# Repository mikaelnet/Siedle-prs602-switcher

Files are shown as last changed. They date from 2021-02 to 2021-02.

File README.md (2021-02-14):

# Siedle-prs602-switcher
Switching module for Siedle PRS602 programmer. 

This is a simple relay card built for Brf Albert that enables
programming of the three Siedle sections without physically
moving the programming cable.

## Function
One of the three sections can be selected either by a push on
one of the corresponding buttons on the case or by sending the
number 1-3 followed by a carrage return on the serial port. 

The relay card has a timeout of 10 minutes after it releases
the relays. The indicating leds blinks slowly two minutes before
the timeout and blinks rapidly one minute before the timeout.
A new 10 minute period is started if the active button or 
corresponding serial command is resent.

## Content
* schematic: Eagle schematic and board layout. The scematic is also expored as a pdf.
* arduino: A simple sketch for the Arduino firmware.
* case: STL files for the case for 3D printng.
* desktop: Simple Windows Form application for controlling the switch box

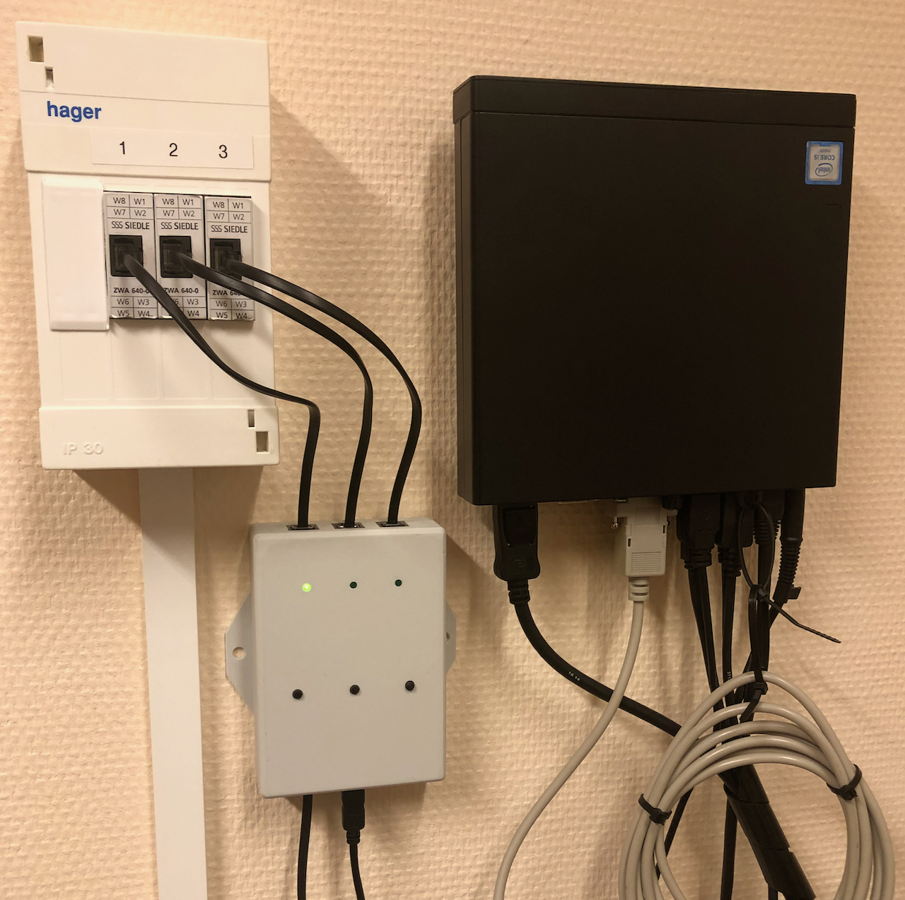
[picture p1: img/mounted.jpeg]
Mounted Switch


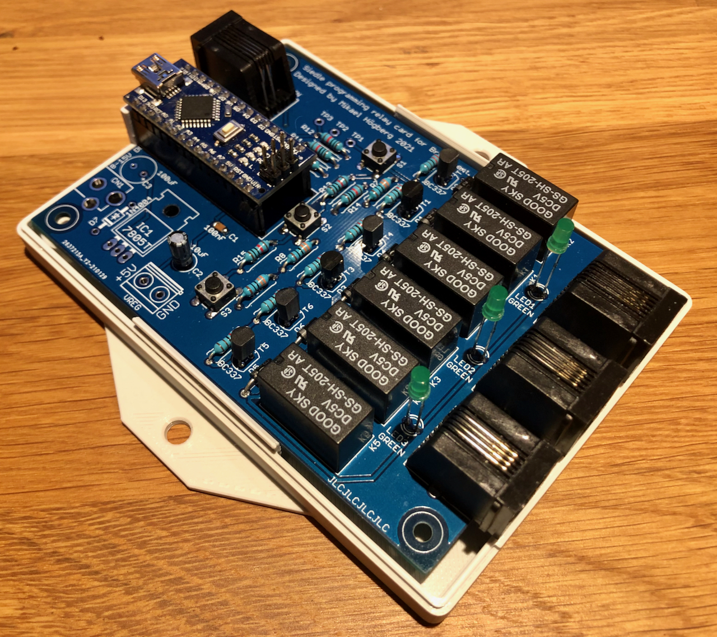
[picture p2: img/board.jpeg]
Board


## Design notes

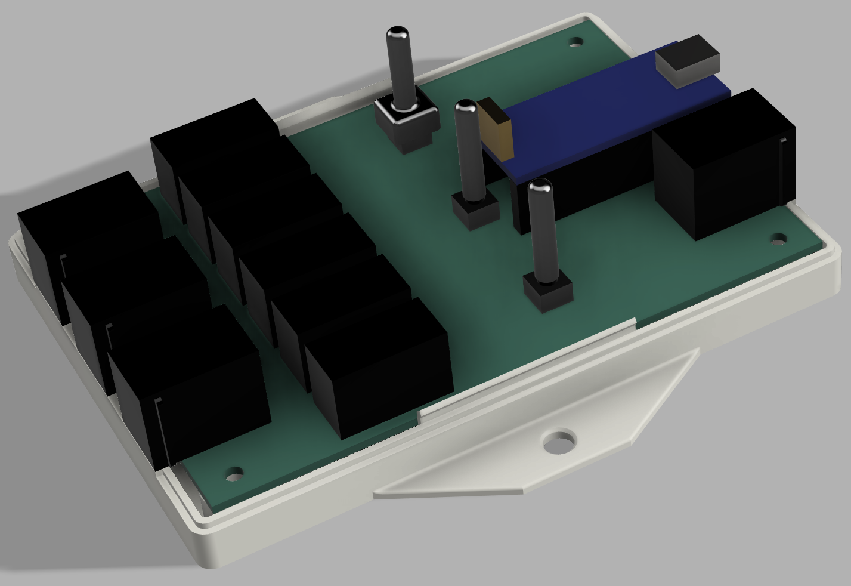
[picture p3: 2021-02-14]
img/fusion360-model.png

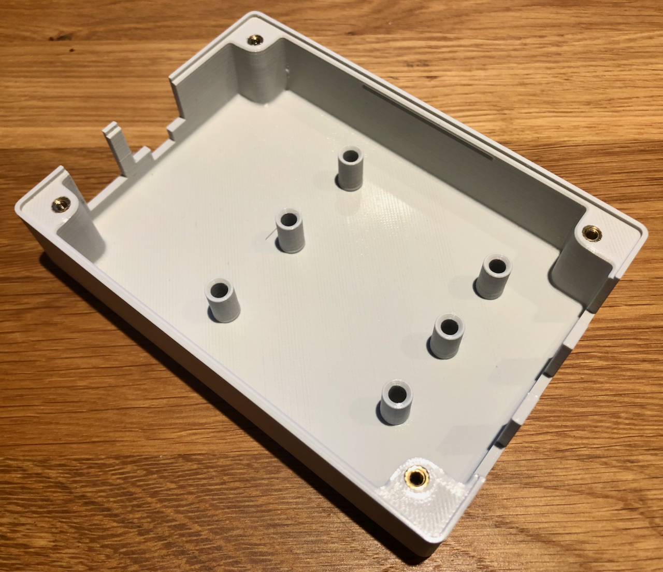
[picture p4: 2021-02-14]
img/case.jpeg

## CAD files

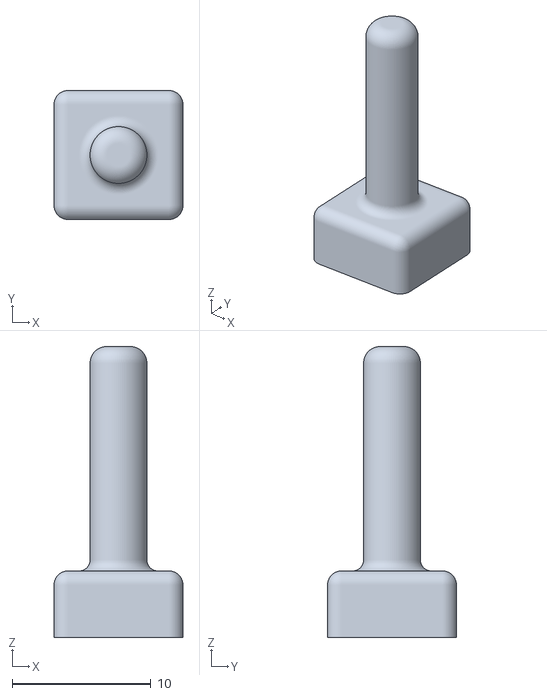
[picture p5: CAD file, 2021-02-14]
case/siedle-case-button.stl
9.30 x 9.30 x 21.0

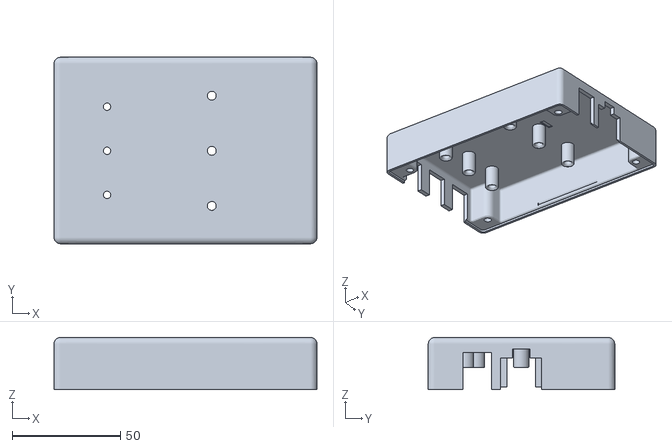
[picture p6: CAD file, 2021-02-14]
case/siedle-case-top.stl
121.2 x 86.0 x 24.0

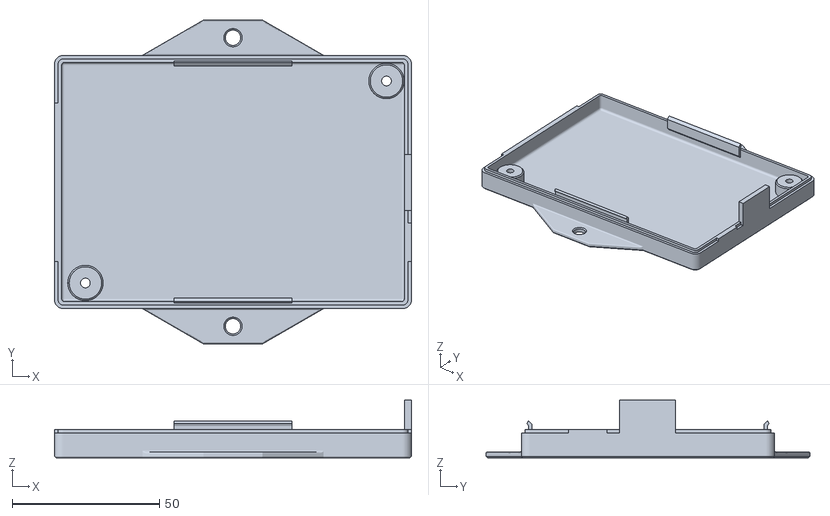
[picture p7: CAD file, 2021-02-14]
case/siedle-case-bottom.stl
121.2 x 110.0 x 19.6

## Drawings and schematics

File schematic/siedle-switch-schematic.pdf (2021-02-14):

# RJ11-out3 ¹N⁴⁰⁰⁴VCC

# GND VCC

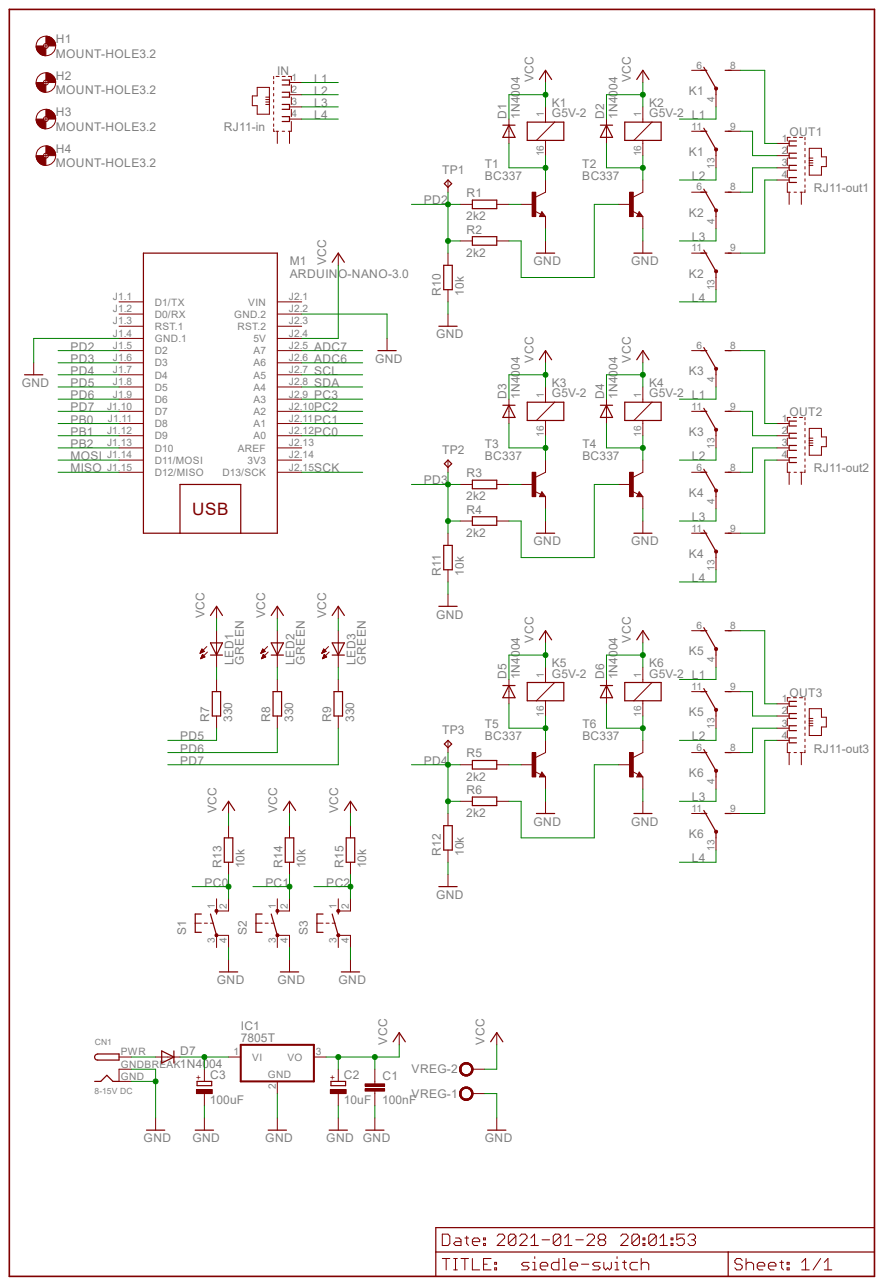
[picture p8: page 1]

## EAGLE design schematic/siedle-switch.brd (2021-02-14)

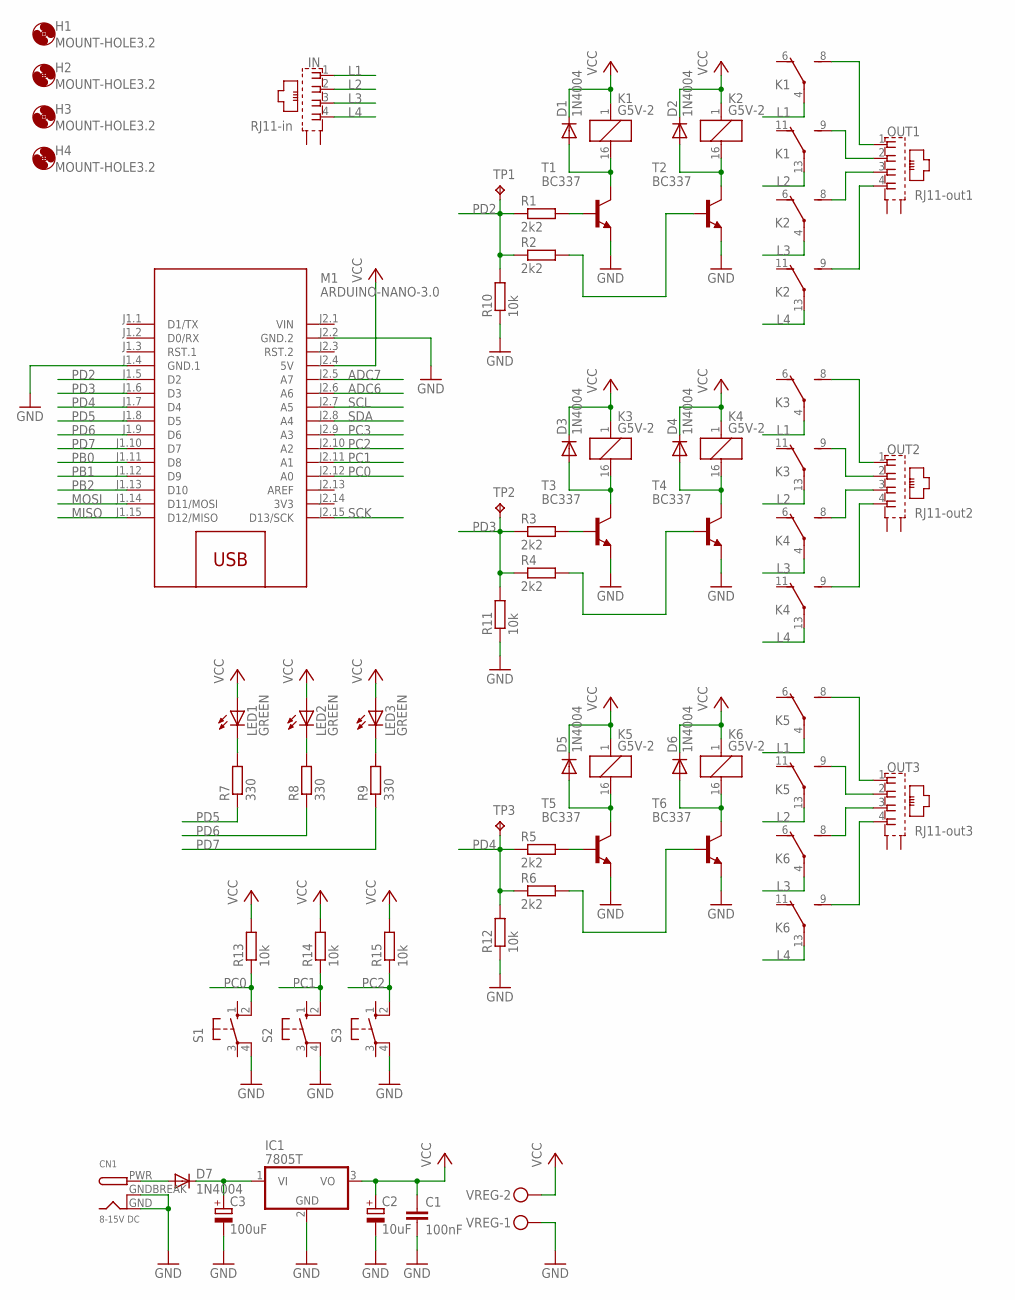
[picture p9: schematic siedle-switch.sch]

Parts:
C1: 100nF; C1206
C2: 10uF; E2,5-5
C3: 100uF; E3,5-8
CN1: 8-15V DC; DCJACK_2MM_PTH
D1, D2, D3, D4, D5, D6, D7: 1N4004; DO41-10
H1, H2, H3, H4: MOUNT-HOLE3.2; 3,2
IC1: 7805T; TO220H
IN: RJ11-in; XRJK-S-01-6-4-0-9M2
K1, K2, K3, K4, K5, K6: G5V-2
LED1, LED2, LED3: GREEN; LED3MM
M1: ARDUINO-NANO-3.0
OUT1: RJ11-out1; XRJK-S-01-6-4-0-9M2
OUT2: RJ11-out2; XRJK-S-01-6-4-0-9M2
OUT3: RJ11-out3; XRJK-S-01-6-4-0-9M2
R1, R2, R3, R4, R5, R6: 2k2; 0309/10
R7, R8, R9: 330; 0309/10
R10, R11, R12, R13, R14, R15: 10k; 0309/10
S1, S2, S3: 10-XX; B3F-10XX
T1, T2, T3, T4, T5, T6: BC337; TO92
TP1, TP2, TP3: TPPAD1-13; P1-13
VREG: MKDSN1,5/2-5,08

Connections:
3V3: M1.J2.14 (3V3)
ADC6: M1.J2.6 (A6)
ADC7: M1.J2.5 (A7)
GND: C1.2, C2.-, C3.-, CN1.GND, CN1.GNDBREAK, IC1.2 (GND), M1.J1.4 (GND.1), M1.J2.2 (GND.2), R10.1, R11.1, R12.1, S1.4 (P1), S2.4 (P1), S3.4 (P1), T1.1 (E), T2.1 (E), T3.1 (E), T4.1 (E), T5.1 (E), T6.1 (E), VREG.1
L1: IN.1, K1.4, K3.4, K5.4
L2: IN.2, K1.13, K3.13, K5.13
L3: IN.3, K2.4, K4.4, K6.4
L4: IN.4, K2.13, K4.13, K6.13
MISO: M1.J1.15 (D12/MISO)
MOSI: M1.J1.14 (D11/MOSI)
unnamed: D6.A, K6.16 (2), T6.3 (C)
unnamed: D5.A, K5.16 (2), T5.3 (C)
unnamed: R5.2, T5.2 (B)
unnamed: R6.2, T6.2 (B)
unnamed: K1.9 (S), OUT1.2
unnamed: K1.8 (S), OUT1.1
unnamed: K2.8 (S), OUT1.3
unnamed: K2.9 (S), OUT1.4
unnamed: D1.A, K1.16 (2), T1.3 (C)
unnamed: R1.2, T1.2 (B)
unnamed: LED3.K (C), R9.2
unnamed: D2.A, K2.16 (2), T2.3 (C)
unnamed: R2.2, T2.2 (B)
unnamed: K3.9 (S), OUT2.2
unnamed: K4.8 (S), OUT2.3
unnamed: K4.9 (S), OUT2.4
unnamed: K3.8 (S), OUT2.1
unnamed: K5.9 (S), OUT3.2
unnamed: K6.8 (S), OUT3.3
unnamed: K6.9 (S), OUT3.4
unnamed: K5.8 (S), OUT3.1
unnamed: R3.2, T3.2 (B)
unnamed: D3.A, K3.16 (2), T3.3 (C)
unnamed: D4.A, K4.16 (2), T4.3 (C)
unnamed: LED2.K (C), R8.2
unnamed: LED1.K (C), R7.2
unnamed: R4.2, T4.2 (B)
unnamed: CN1.PWR, D7.A
unnamed: C3.+, D7.C, IC1.1 (VI)
PB0: M1.J1.11 (D8)
PB1: M1.J1.12 (D9)
PB2: M1.J1.13 (D10)
PC0: M1.J2.12 (A0), R13.1, S1.2 (S1)
PC1: M1.J2.11 (A1), R14.1, S2.2 (S1)
PC2: M1.J2.10 (A2), R15.1, S3.2 (S1)
PC3: M1.J2.9 (A3)
PD2: M1.J1.5 (D2), R1.1, R2.1, R10.2, TP1.TP
PD3: M1.J1.6 (D3), R3.1, R4.1, R11.2, TP2.TP
PD4: M1.J1.7 (D4), R5.1, R6.1, R12.2, TP3.TP
PD5: M1.J1.8 (D5), R7.1
PD6: M1.J1.9 (D6), R8.1
PD7: M1.J1.10 (D7), R9.1
SCK: M1.J2.15 (D13/SCK)
SCL: M1.J2.7 (A5)
SDA: M1.J2.8 (A4)
VCC: C1.1, C2.+, D1.C, D2.C, D3.C, D4.C, D5.C, D6.C, IC1.3 (VO), K1.1, K2.1, K3.1, K4.1, K5.1, K6.1, LED1.A, LED2.A, LED3.A, M1.J2.4 (5V), R13.2, R14.2, R15.2, VREG.2
VIN: M1.J2.1 (VIN)

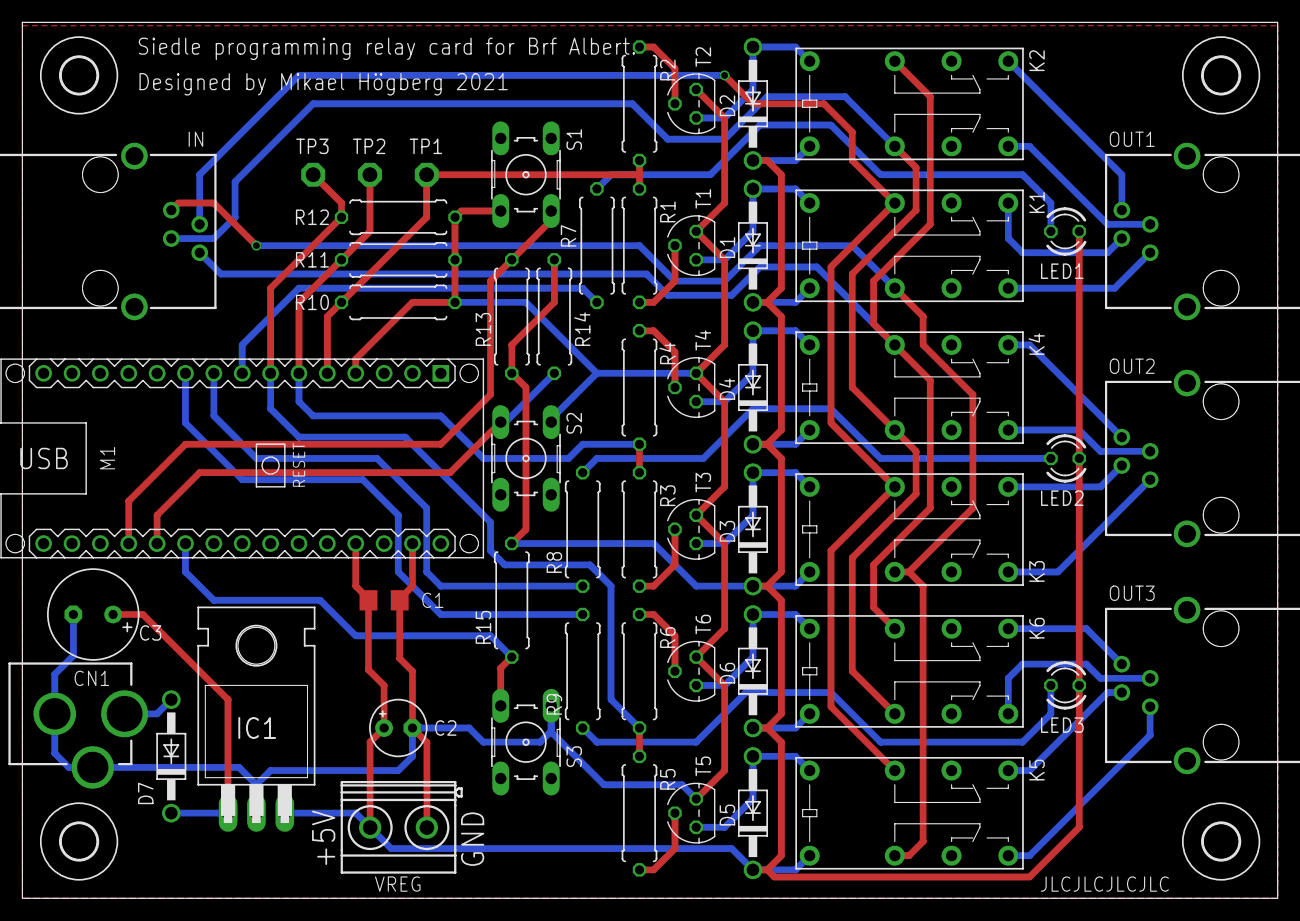
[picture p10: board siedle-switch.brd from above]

Board: 4 copper layers, 112.4 x 78.4 mm, 58 parts (0 on the bottom side), 44 nets.

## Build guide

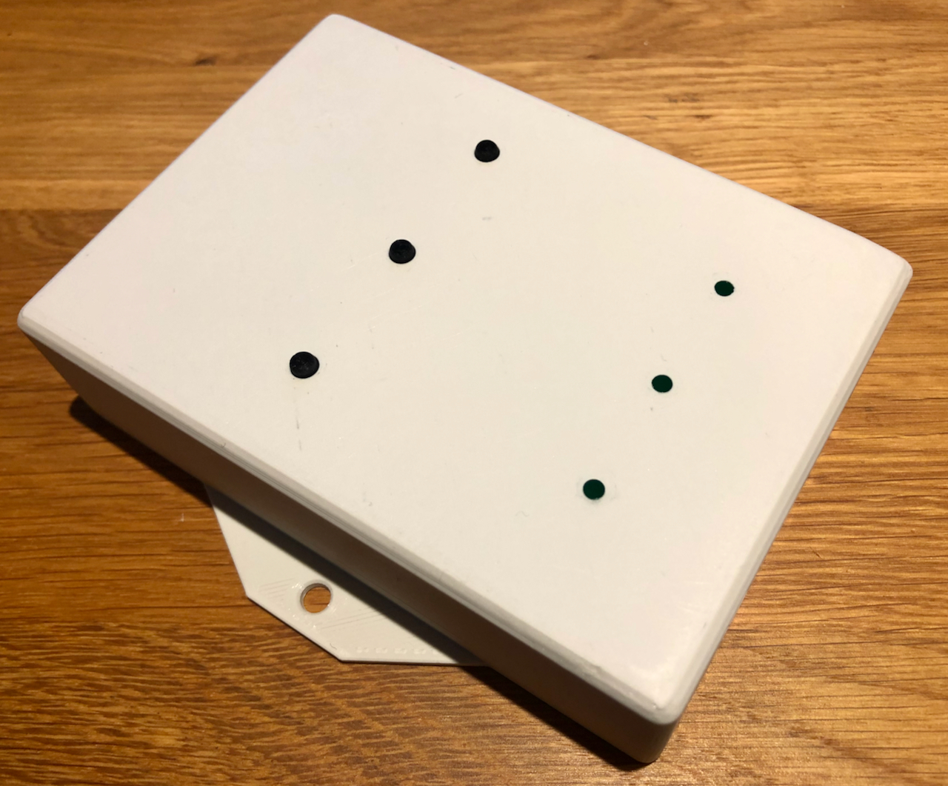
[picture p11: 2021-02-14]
img/assembled.jpeg

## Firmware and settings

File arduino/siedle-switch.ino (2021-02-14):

/*
 * Controller of Seidle programmer
 */

// HIGH drives the relays, LOW releases them
#define RELAY1  2
#define RELAY2  3
#define RELAY3  4

// LOW turns on leds, HIGH turns them off
#define LED1    5
#define LED2    6
#define LED3    7

#define SWITCH1 A0
#define SWITCH2 A1
#define SWITCH3 A2

#define RELAY_TIMEOUT   (10*60*1000L)
#define RELAY_TIMEOUT_WARN1 (8*60*1000L)
#define RELAY_TIMEOUT_WARN2 (9*60*1000L)

String inputString = "";
bool commandRecieved = false;

unsigned long relayTimer;

int relayPins[3] = { RELAY1, RELAY2, RELAY3 };
int ledPins[3] = { LED1, LED2, LED3 };
int switchPins[3] = { SWITCH1, SWITCH2, SWITCH3 };
int activeRelay = 0;

void resetTimer ()
{
  relayTimer = millis();
}

void setRelay (int relay)
{
  relay &= 0x03;    // Ensure not out of bounds
  resetTimer();
  // Do nothing if expected relay is already active
  if (relay == activeRelay) {
    return;
  }

  // Release all relays
  for (int i=0 ; i < 3 ; i ++) {
    digitalWrite (relayPins[i], LOW);
  }
  delay(100); // Wait a short while to ensure the relay is released

  // Enable relay, if any selected
  if (relay > 0) {
    digitalWrite (relayPins[relay-1], HIGH);
    delay(50);  // Wait a short while to ensure the relay is active
  }
  
  activeRelay = relay;
  Serial.println (relay);
}

void setLed (int led, bool on)
{
  led &= 0x03;
  if (led > 0) {
    digitalWrite (ledPins[led-1], on ? LOW : HIGH);
  }
}

void setAllLedOff ()
{
  for (int led=1 ; led <= 3 ; led ++) {
    setLed (led, false);
  }
}

int getButton ()
{
  for (int i=0 ; i < 3 ; i ++) {
    int btn = digitalRead(switchPins[i]);
    if (btn == LOW)
      return i+1;
  }
  return 0;
}

void updateInterface ()
{
  if (activeRelay == 0) 
    return;

  unsigned long timeLapsed = millis() - relayTimer;

  // Turn off led at timeout
  if (timeLapsed > RELAY_TIMEOUT) {
    setLed (activeRelay, false);
    setRelay (0);
    return;
  }

  // Fast blink close to timeout
  if (timeLapsed > RELAY_TIMEOUT_WARN2) {
    setLed (activeRelay, timeLapsed % 200 > 100);
    return;
  }

  // Slow blink before timeout
  if (timeLapsed > RELAY_TIMEOUT_WARN1) {
    setLed (activeRelay, timeLapsed % 1000 > 500);
    return;
  }
}

void invokeCommand (int relay) 
{
  setRelay (relay);
  setAllLedOff();
  setLed (relay, true);
}

void sendInfo() {
  // TODO: Add more content here
  Serial.println ("# Siedle output switcher");
  Serial.println ("# Send relay ID followed by a newline to activate port");
  Serial.println ("# Relay ID is 1, 2 or 3. ");
  Serial.println ("# Send 0 (zero) followed by newline to disable all relays.");
  Serial.println ("# All relays are automatically released after 5 minutes.");
  Serial.println ("# Empty newline repeats this message.");
}

void setup() {
  // Set the relay driver pins to output and 
  // ensure all drivers are disabled
  for (int i=0 ; i < 3 ; i ++) {
    pinMode (relayPins[i], OUTPUT);
    digitalWrite (relayPins[i], LOW); // Relays enables at HIGH

    pinMode (ledPins[i], OUTPUT);
    digitalWrite (ledPins[i], HIGH);  // Leds lit at LOW

    pinMode (switchPins[i], INPUT);   // Switches are pressed at LOW
  }
  
  inputString.reserve(80);

  Serial.begin(9600);
  while (!Serial) {
    // cycle leds here as boot
  }

  sendInfo();
  Serial.println ("0");
}

void serialEvent() {
  while (Serial.available()) {
    char inChar = (char)Serial.read();
    
    if (inChar == '\b') {   // Backspace. Remove last character
      int length = inputString.length();
      if (length > 0) {
        inputString.remove(length - 1);
      }
    }
    else if (inChar == '\r' || inChar == '\n') {
      commandRecieved = true;
    }
    else {
      inputString += inChar;
    }
  }
}

void loop() {
  updateInterface();
  int button = getButton();
  if (button > 0) {
    invokeCommand (button);
  }
  
  if (commandRecieved) {
    if (inputString.length() != 1) {
      sendInfo();
    }
    else {
      char ch = inputString[0];
      if (ch >= '0' && ch <= '3') {
        invokeCommand (ch - '0');        
      }
    }
    inputString = "";
    commandRecieved = false;
  }
}

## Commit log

2021-02-14 Arduino Nano firmware
2021-02-14 Case STL files
    [siedle-case-bottom.stl, siedle-case-button.stl, siedle-case-top.stl]
2021-02-14 Added BOM

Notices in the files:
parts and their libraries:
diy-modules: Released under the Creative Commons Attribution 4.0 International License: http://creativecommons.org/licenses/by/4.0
